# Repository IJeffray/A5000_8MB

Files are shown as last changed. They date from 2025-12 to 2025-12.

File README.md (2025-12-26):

# A5000 8MB

December 2025

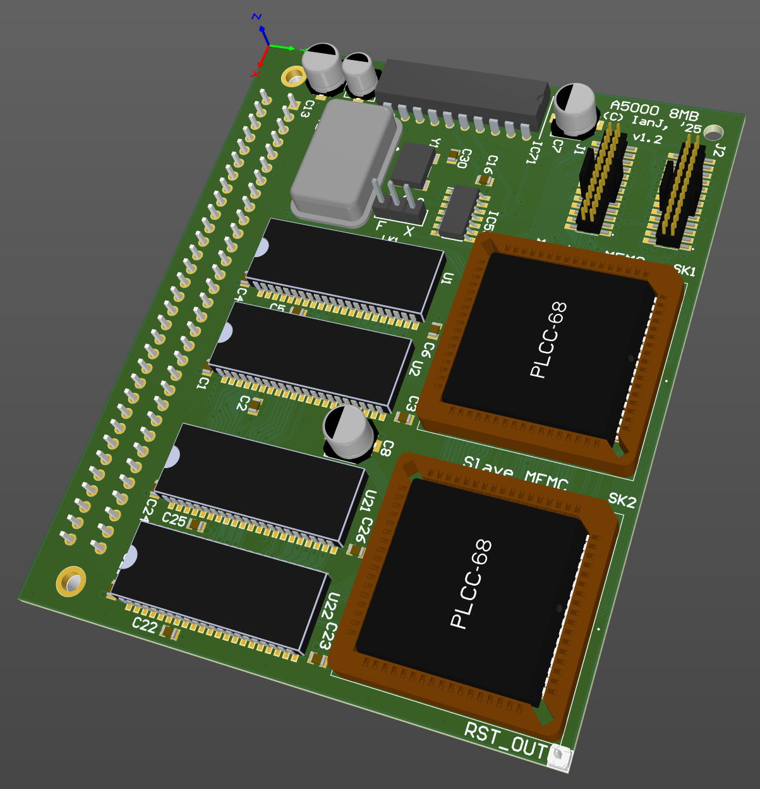
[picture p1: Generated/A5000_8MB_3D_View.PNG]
3D View


An 8MB board for Acorn A5000.  Disconnects all the motherboard RAM so can be used on any A5000, even one with no RAM on board.
Uses my MEMC_Dual_IDCs or MEMC_Plug_Dual_IDCs adapter and a pair of short 1.27mm 26 way IDC cables for MEMC connection, purely to account for variability of positioning of the MEMC socket on the motherboard.
In common with other 8MB upgrades, it does require either a MEMC socket on the motherboard - so either an 'Alpha' variant board, or one where the MEMC has been socketed after market - or soldering of the MEMC_Dual_IDCs board directly to the motherboard.
Because the onboard RAM is not used, this board provides its own clock to allow the MEMCs to be overclocked and the RAM run at 20MHz or greater - a noticable performance boost from the stock 12MHz RAM on the motherboard.

Due to the PAL design being simply lifted from the A540, one track cut (between IC5 pin 2 and its close-by via) and one fine patch wire (from this board to the via right next to ARM3 reset pin 32) may be required for most reliable start up - holding-off reset to the ARM3 until the MEMC sync process is complete.  In practice, this hasn't been required so far.

The 1.0 design has been built and tested up to 50MHz (16.66MHz RAM) - there was one design fault with DBE not tracked to the MEMC connector, requiring a tricky cut and strap fix - this was corrected in the 1.1 design which was never actually built.  The 1.1 design also adds a manual moveable link for clock selection internal / external so that the onboard overclock oscillator may be left populated and only activated when desired.  A further update as version 1.2 replaces the original FFC connector with the pair of 26 way IDCs (one 31.5mm long and another 53.5mm) for easier soldering and cabling.  A position for a DIP oscillator/socket was also added to accommodate easier tweaking of the clock speed and more SMT components were moved to the bottom side with the plan that a single-side load SMT assembly of jellybean parts may be undertaken.  The 1.2 design has been been built and tested up to 16.66MHz.

## Licence

No warranty is provided, and this work is used at your own risk.  

Licenced as CC BY-SA 4.0

Copyright 2025 Ian Jeffray

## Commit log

2023-04-10 Initial commit - schematic ok, layout rough placement only
    [A5000_8MB.PrjPcb, A5000_8MB.SchDoc, Acorn.PcbLib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]
2024-01-02 Change from 'Atomwide' PALs to that from the A540 - glue logic copied from A3000 8MB design. Layout updated, but no routing yet.
    [A5000_8MB.PrjPcb, A5000_8MB.SchDoc, A5000_8MB_Glue.SchDoc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]
2024-01-02 Add optional (likely default) population option for using motherboard clock source rather than local osc.
    [A5000_8MB.SchDoc, A5000_8MB_Glue.SchDoc]
2024-03-21 Fully routed
    [A5000_8MB.PrjPcb, A5000_8MB.SchDoc, A5000_8MB_Slave.SchDoc]
2025-04-19 Rarrange to have an Arm3 reset output wire
    [A5000_8MB.PrjPcb, A5000_8MB.SchDoc, A5000_8MB_Glue.SchDoc]
2025-04-20 Update project status. Clean up Output job / DNF parts for JLCPCB build.
    [A5000_8MB.PrjPcb, A5000_8MB.SchDoc, A5000_8MB_Glue.SchDoc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]
2025-04-20 Correct project metadata
    [A5000_8MB.PrjPcb, A5000_8MB.SchDoc]
2025-04-20 Correct pin-order of main RAM connector - was misled with R vs C type connector. Also simplify the design slightly by having only one set of data bus series resistors.
    [A5000_8MB.PrjPcb, A5000_8MB.SchDoc, A5000_8MB_MEMCs.SchDoc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]
2025-05-06 Correct DBE assignment on FFC connector. Add LK1 for easy fast/external clock selection so onboard overclock oscillator can always be fitted. Remove two support holes and change the remaining to be u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
    [A5000_8MB.PrjPcb, A5000_8MB_Glue.SchDoc, A5000_8MB_MEMCs.SchDoc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]
2025-12-10 Change to a pair of 26 way 1.27mm IDCs rather than the FFC for easier building and cable wrangling. Add a DIP socket for onboard oscillator. More jellybean SMT parts moved to the underside.
    [A5000_8MB.PrjPcb, A5000_8MB.pcbdoc, A5000_8MB_Glue.SchDoc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]
2025-12-26 Update build status and record IDC cable lengths.
